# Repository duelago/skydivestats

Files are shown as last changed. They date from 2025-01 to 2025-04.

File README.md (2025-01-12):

# SkyWin Stats

<h1>Wall mounted instrument that displays jump data</h1>

alti

<h2>End user installation instructions</h2>

1. Plug in the Altimeter to the wall with a usb charger and a micro usb-cable<br>
2. Search your wifi networks and connect to SkyWin Stats<br>
3. A captive portal pops up. If not start a browser and go to http://192.168.4.1<br>
4. Give your wifi credentials. The altimeter will get an IP on your wifi network<br>
5. Connect to http://skywinstats.local (You must be connected to the same wifi with your device) <br>
5b. If above does not work. Download the app Fing on your phone and scan your network to figure out the new IP for the Altimeter. (It shows up as skywinstats or Generic device) <br>
5c. Browse your Altimeter webservers IP-address. In my case I got the IP http://192.168.8.111 You have another IP<br>
6. Login on website. user: skydive  passwd: jump<br>
7. Add the url to your dropzone JSON API, SkyWinOne 24.0.1 or later. (Talk to Jesper Löfberg at SkyWin if you don't know how)<br>
   (Demo looks like this: https://demo.skywin.se/api/v1/reports/jump-stats.json )<br>
8. Done! The url is stored in EEPROM and will survive a power failure. The unit will also recalibrate itself if it loses power.

<h2>How to build your own SkyWin stats altimeter</h2>

We use a 3D printed altimeter to show jump statistics from the Skywin database<p>

Demo JSON url from SkyWin: https://demo.skywin.se/api/v1/reports/jump-stats.json<br>
Demo JSON url with more random numbers between reload: http://www.hoppaiplurret.se/jump.php
<br><br>
<b>Example output:</b><br> {"name":"jump-stats","params":"[jumpYear:2025]","result":[{"Total":114,"Other":90,"AFF student":0,"Static line":0,"Manual":0,"Tandem":0,"Video/photo (tandem)":0,"Cockpit":0,"Display":24,"Competition":0}],"size":2}

Idea is to use a stepper motor and a hall sensor and to move the motor to represent the number of jumps made the current season. The first version here is for tandems.<br><br>
<b>Steps to do:</b>
<br>
- 3D print the parts. It is easiest on a Bambulab with AMS, but possible on a normal printer with two color changes.Print the two back covers with connectors so you can open up the construction after it is finished. 

<b>Buy the following:</b><br>
- Wemos d1 mini v3 :https://www.aliexpress.com/item/4000030041652.html<br>
- Stepper motor with driver board: 28BYJ-48-5V + Driver Board ULN2003: https://www.aliexpress.com/item/1005006781616785.html<br>
- KY-024 hall sensor: https://www.aliexpress.com/item/1005007847486915.html<br>
- Magnets: https://www.aliexpress.com/item/1005004351705901.html<br>
- M 2.5 screws<br>
- Dupont cables for soldering<br>
- Superglue to glue the 3D printed part for the components to the backside of the watchface<br>
- Microusb cable
koppling

You need to press fit 3 magnets to the altimeter arrow. One drop of super glue is also good for safety measures so you don't lose the magnets. Make sure that you place the magnets in the correct direction. The hall sensor will only work with the correct polarity. When set, play around with the calibaration setting in the code to make sure the arrow calibrates to 0 at boot. It can differ a few degrees depending on the position of the hall sensor.

Compile the code in Arduino IDE. Add the ESP8266 framework and the necessary libraries.

magnet

konstruktion


<br>

<br>

<br>


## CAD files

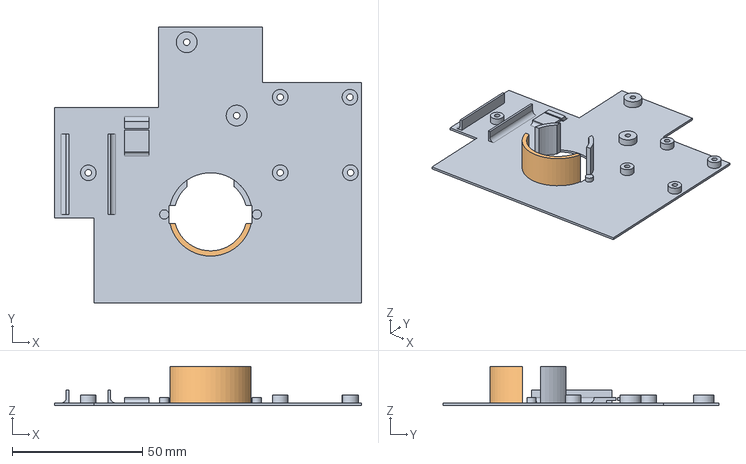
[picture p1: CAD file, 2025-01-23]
barigo-components.step
118.0 x 106.0 x 15.0 mm

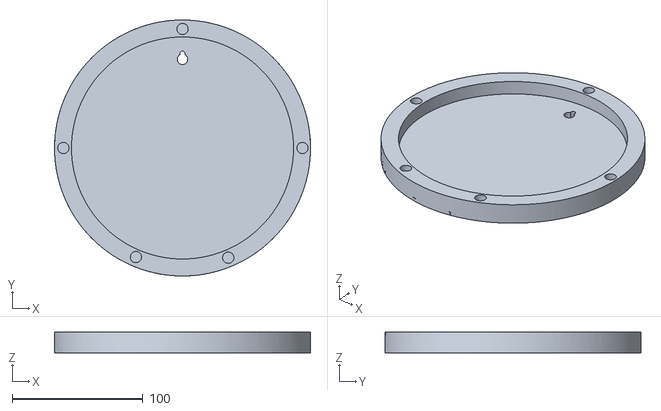
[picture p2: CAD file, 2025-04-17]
urverk/barigo-back-cover-part2-utan-usb.stl
196.0 x 196.0 x 15.8

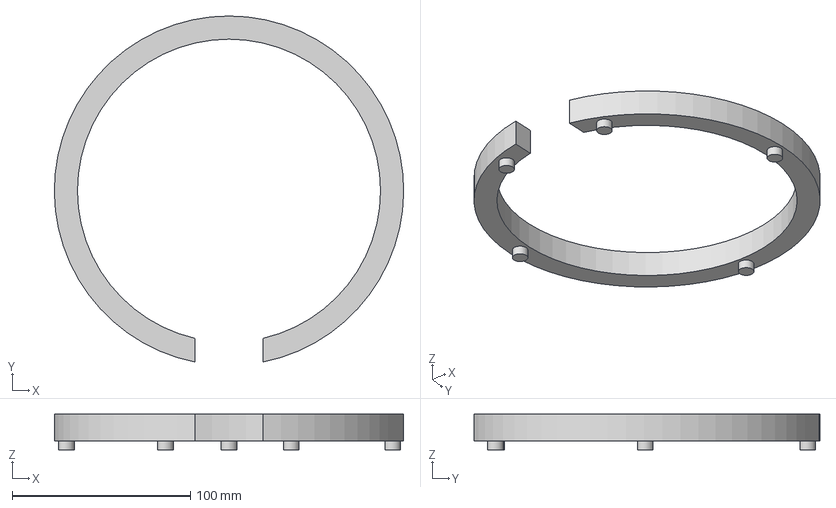
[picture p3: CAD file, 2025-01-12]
barigo-back-cover-part1.step
196.0 x 194.1 x 20.0 mm

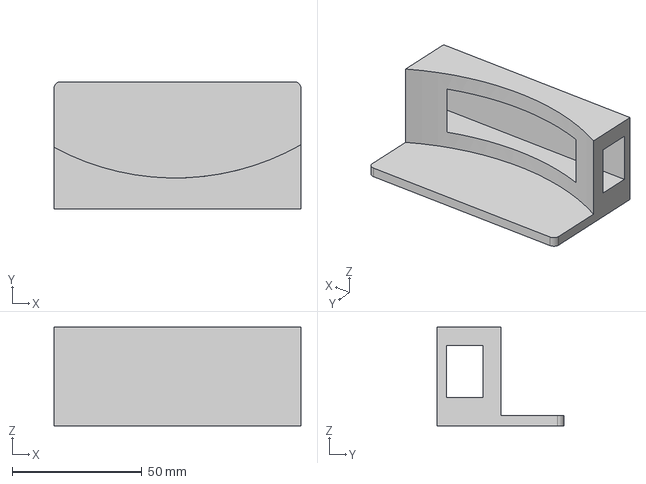
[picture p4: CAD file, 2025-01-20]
urverk/barigo-table-stand.step
95.0 x 49.0 x 38.0 mm

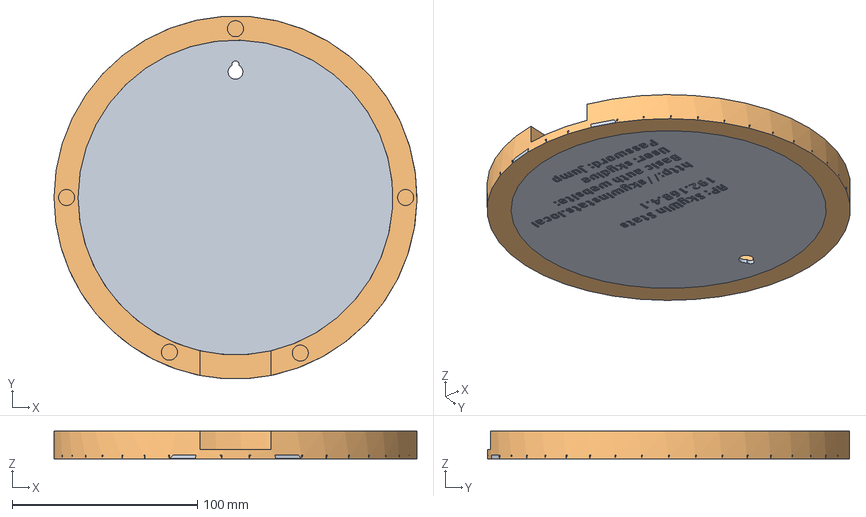
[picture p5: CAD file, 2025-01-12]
barigo-back-cover-part2.step
196.0 x 195.6 x 15.0 mm

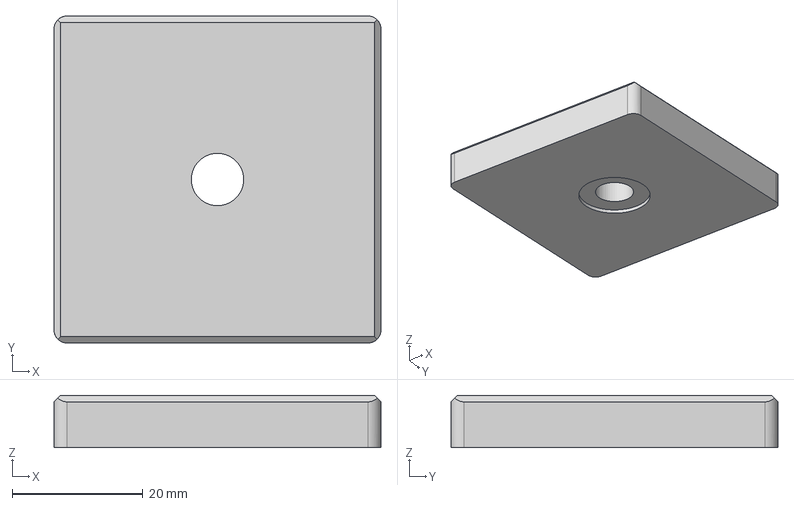
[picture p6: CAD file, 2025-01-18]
urverk/barigo-clock-spacer.step
50.0 x 50.0 x 8.00 mm

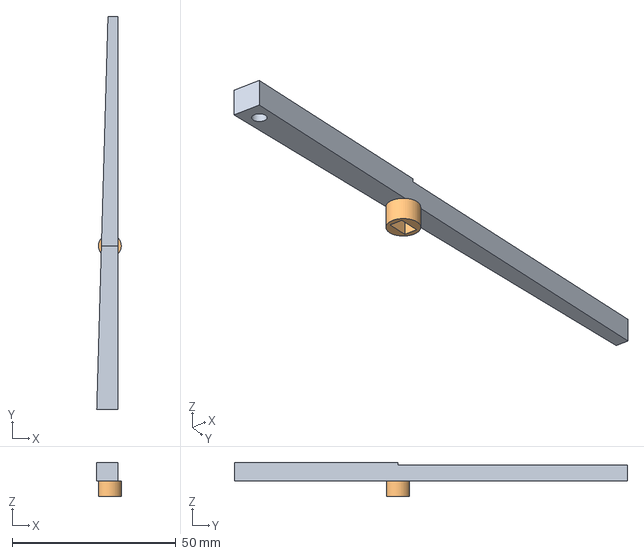
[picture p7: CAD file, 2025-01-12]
barigo-arrow.step
7.50 x 120.0 x 10.4 mm

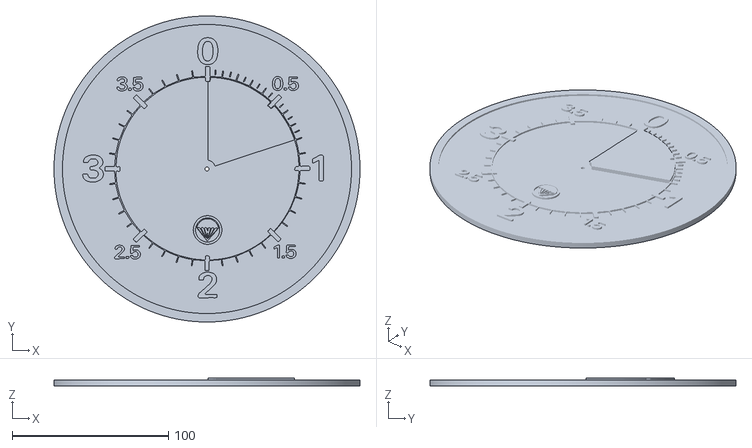
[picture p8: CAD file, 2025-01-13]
urverk/barigo-alternative-face.stl
195.9 x 195.9 x 5.04

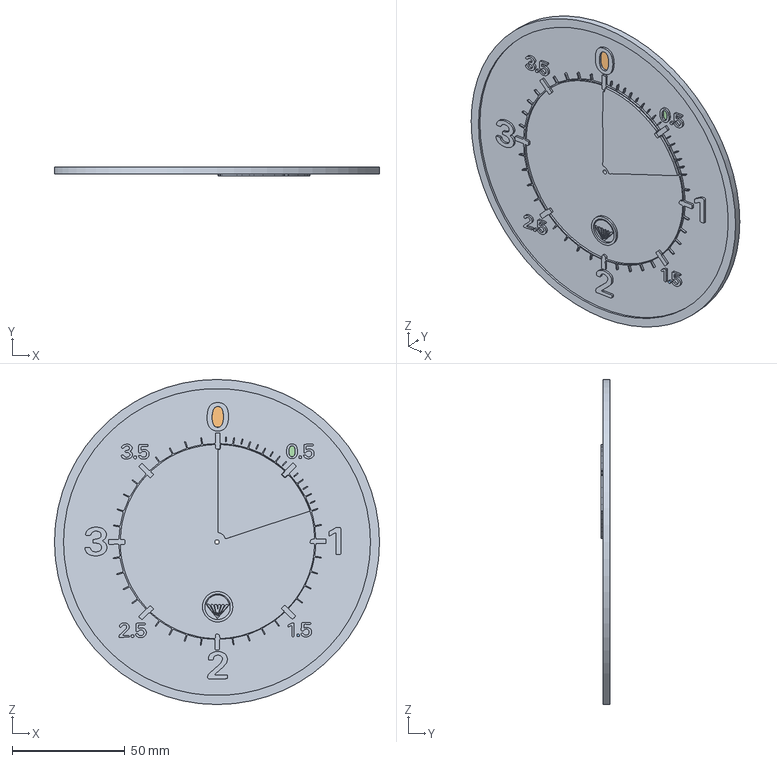
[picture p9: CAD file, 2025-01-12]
barigo-alternative-face.step
144.0 x 4.00 x 144.0 mm

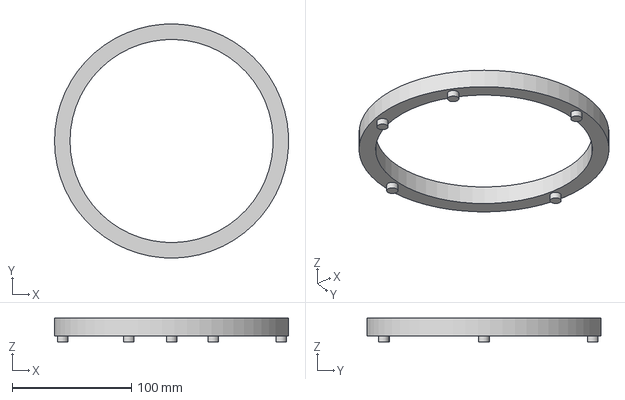
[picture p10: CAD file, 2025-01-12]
urverk/barigo-back-cover-part1-utan-usb.step
195.9 x 195.9 x 20.0 mm

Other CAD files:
urverk/barigo-face.stl
barigo-face.step

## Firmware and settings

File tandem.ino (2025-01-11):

#include <ESP8266WiFi.h>
#include <ESP8266HTTPClient.h>
#include <ESP8266WebServer.h>
#include <ESP8266mDNS.h>
#include <ArduinoJson.h>
#include <AccelStepper.h>
#include <WiFiManager.h>
#include <EEPROM.h>
#include <ElegantOTA.h>

// Pin definitions
#define IN1 D1
#define IN2 D2
#define IN3 D3
#define IN4 D4
#define HALL_SENSOR_PIN D5

// Variables
ESP8266WebServer server(80);
AccelStepper stepper(AccelStepper::HALF4WIRE, IN1, IN3, IN2, IN4);
String jsonUrl;
int previousTandem = 0;
unsigned long lastFetchTime = 0;

// === Kalibreringsvinkel ===
// Justera denna vinkel för att kalibrera pilens position
const int CALIBRATION_ANGLE = 199;  // Ändra värdet här för att justera vinkel

// === Tid mellan uppdatering ===
// const unsigned long fetchInterval = 20000; // 20 seconds for testing
const unsigned long fetchInterval = 3600000; // Kolla en gång per timme 

const char* authUsername = "skydive";
const char* authPassword = "jump";

// Calibration state
bool isCalibrating = true;

void setup() {
  Serial.begin(115200);
  EEPROM.begin(512);

  // Configure Hall sensor pin
  pinMode(HALL_SENSOR_PIN, INPUT_PULLUP);

  // Load URL from EEPROM
  loadUrlFromEEPROM();

  WiFiManager wifiManager;
  wifiManager.autoConnect("SkyWin Stats");
  Serial.println("WiFi connected!");

  // Initialize mDNS
  if (MDNS.begin("skywinstats")) {
    Serial.println("mDNS responder started. Access your ESP at http://skywinstats.local");
    // Add web service to mDNS
    MDNS.addService("http", "tcp", 80);
  } else {
    Serial.println("Error starting mDNS responder!");
  }

  // Set up web server routes
  server.on("/", HTTP_GET, handleRoot);
  server.on("/set-url", HTTP_POST, handleSetUrl);
  ElegantOTA.begin(&server);
  server.begin();
  Serial.println("Web server started.");

  // Configure stepper motor
  stepper.setMaxSpeed(1000);
  stepper.setAcceleration(500);

  // Start calibration process in non-blocking way
  calibrateToZero();
}

void loop() {
  server.handleClient();
  MDNS.update(); // Handle mDNS requests
  

  // Check if it's time to fetch the data
  if (millis() - lastFetchTime >= fetchInterval) {
    fetchData();
    lastFetchTime = millis();
  }

  // If still calibrating, let the motor run in background
  if (isCalibrating) {
    stepper.run();
  } else {
    // If the motor is not moving, disable the outputs to avoid unnecessary torque
    if (stepper.distanceToGo() == 0) {
      stepper.disableOutputs();  // Disable motor outputs to stop torque
    }
  }
}


void calibrateToZero() {
  Serial.println("Calibrating to zero position...");
  delay(1000);  // Delay to allow initialization

  // Move motor in reverse direction continuously
  stepper.setMaxSpeed(500);
  stepper.setSpeed(-500);
  stepper.moveTo(-1000000);  // Arbitrary large negative number to keep the motor moving

  while (true) {
    stepper.run();  // Continuously run the motor

    // Print status occasionally to reduce flooding
    static unsigned long lastPrintTime = 0;
    if (millis() - lastPrintTime > 500) {
      Serial.println("Searching for Hall sensor...");
      lastPrintTime = millis();
    }

    // If the Hall sensor is triggered, stop the motor and set current position to zero
    if (digitalRead(HALL_SENSOR_PIN) == LOW) {  // Assuming LOW indicates sensor triggered
      stepper.stop();  // Stop the motor
      stepper.setCurrentPosition(0);  // Set the current position to zero
      Serial.println("Hall sensor detected! Setting current position to zero.");

      // Move stepper to get to 0. Adjust the degrees so the arrow is straight up
      int stepsFor110Degrees = -2048 * CALIBRATION_ANGLE / 360;  // Calculate steps for CALIBRATION_ANGLE degrees
      stepper.moveTo(stepsFor110Degrees);
      stepper.runToPosition();  // Move and stop

      // Update the new zero point
      stepper.setCurrentPosition(0);
      Serial.println("New zero point set after moving " + String(CALIBRATION_ANGLE) + " degrees to 0");

      isCalibrating = false;  // Mark calibration as done
      break;
    }
  }
}


void fetchData() {
  if (WiFi.status() == WL_CONNECTED && jsonUrl.length() > 0) {
    WiFiClient client;
    HTTPClient http;

    http.begin(client, jsonUrl);

    int httpCode = http.GET();
    if (httpCode == HTTP_CODE_OK) {
      String payload = http.getString();
      Serial.println("Data fetched: " + payload);

      // Update the JSON buffer size to fit the new structure
      DynamicJsonDocument doc(2048);
      DeserializationError error = deserializeJson(doc, payload);

      if (error) {
        Serial.println("Failed to parse JSON!");
        return;
      }

      // Access the "result" array and find "Tandem"
      int tandem = doc["result"][0]["Tandem"];
      Serial.println("Tandem: " + String(tandem));

      // Handle values above 4000
      int baseSteps = map(min(tandem, 4000), 0, 4000, 0, 4096);
      int extraSteps = (tandem > 4000) ? tandem - 4000 : 0;
      int totalSteps = baseSteps + extraSteps;

      // Calculate steps to move
      int stepsToMove = totalSteps - stepper.currentPosition();
      stepper.moveTo(totalSteps);

      // Re-enable motor before moving
      stepper.enableOutputs();

      // Run the motor to the new position
      stepper.runToPosition();

      previousTandem = tandem;

      // After movement, disable the motor to avoid torque
      stepper.disableOutputs();
    } else {
      Serial.println("Error fetching data: " + String(httpCode));
    }

    http.end();
  } else {
    Serial.println("WiFi not connected or URL not set");
  }
}


void handleRoot() {
  if (!server.authenticate(authUsername, authPassword)) {
    return server.requestAuthentication();
  }

  String html = R"rawliteral(
    <!DOCTYPE html>
    <html lang="en">
    <head>
      <meta charset="UTF-8">
      <meta name="viewport" content="width=device-width, initial-scale=1.0">
      <title>SkyWin Stats</title>
      <style>
        body {
          font-family: 'Arial', sans-serif;
          background-color: #f0f8ff;
          margin: 0;
          padding: 20px;
        }
        h1 {
          color: #333;
          text-align: center;
        }
        h3 {
          color: #696969;
          text-align: center;
        }
        form {
          max-width: 400px;
          margin: 0 auto;
          background-color: #ffffff;
          padding: 20px;
          border-radius: 10px;
          box-shadow: 0 4px 8px rgba(0, 0, 0, 0.1);
        }
        label {
          display: block;
          margin-bottom: 8px;
          font-weight: bold;
        }
        input[type="text"] {
          width: 100%;
          padding: 10px;
          margin-bottom: 20px;
          border: 1px solid #ccc;
          border-radius: 5px;
        }
        input[type="submit"] {
          width: 100%;
          padding: 10px;
          background-color: #007bff;
          color: #fff;
          border: none;
          border-radius: 5px;
          cursor: pointer;
        }
        input[type="submit"]:hover {
          background-color: #0056b3;
        }
        a {
          display: block;
          text-align: center;
          margin-top: 20px;
          color: #007bff;
          text-decoration: none;
        }
        a:hover {
          color: #0056b3;
        }
        @media (max-width: 600px) {
          body {
            padding: 10px;
          }
          form {
            padding: 15px;
          }
        }
      </style>
    </head>
    <body>
      <h1>SkyWin Stats</h1>
      <form action='/set-url' method='POST'>
        <label for='url'>JSON URL:</label>
        <input type='text' id='url' name='url' value=')rawliteral" + jsonUrl + R"rawliteral('>
        <input type='submit' value='Save'>
      </form>
      <a href='/update'>Firmware Update (OTA)</a>
      <p></p>
      <h3>SkyWinOne 24.0.1 or newer needed for it to work<br>Demo URL to fetch random number of jumps:<br> http://www.hoppaiplurret.se/jump.php </h3><p></p>
    </body>
    </html>
  )rawliteral";

  server.send(200, "text/html", html);
}

void handleSetUrl() {
  if (!server.authenticate(authUsername, authPassword)) {
    return server.requestAuthentication();
  }

  if (server.method() == HTTP_POST) {
    jsonUrl = server.arg("url");
    saveUrlToEEPROM(jsonUrl);
    server.send(200, "text/html", "<html><body><h1>URL Saved!</h1><a href='/'>Back to Home</a></body></html>");
  } else {
    server.send(405, "text/plain", "Method Not Allowed");
  }
}

void loadUrlFromEEPROM() {
  char urlBuffer[100];
  for (int i = 0; i < sizeof(urlBuffer); i++) {
    urlBuffer[i] = EEPROM.read(i);
  }
  jsonUrl = String(urlBuffer);
  jsonUrl.trim();
  Serial.println("Loaded URL: " + jsonUrl);
}

void saveUrlToEEPROM(String url) {
  for (int i = 0; i < url.length() && i < 100; i++) {
    EEPROM.write(i, url[i]);
  }
  EEPROM.write(url.length(), '\0'); // Null-terminate the string
  EEPROM.commit();
  Serial.println("URL saved to EEPROM: " + url);
}

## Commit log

2025-01-08 Add files via upload
    File to mount stepper motor, Wemos D1 mini v3 and hall sensor
    [barigo-components.step]
2025-01-10 Add files via upload
    Split this file in two in Prusa slicer and add connectors to be able to open the construction after it is finished
    [barigo-back-cover-split.step]
2025-01-12 A simple table stand
    Quick and dirty table stand
    [barigo-table-stand.step]
2025-01-12 Add files via upload
    Back cover utan hål för USB-sladd. Används för de som vill stoppa i ett vanligt urverk och sisa tiden. Printas i två delar så man enkelt kan öppna upp och byta batteri
    [barigo-back-cover-part1-utan-usb.step, barigo-back-cover-part2-utan-usb.step]
2025-01-18 Add files via upload
    Köpte ett urverk från AliExpress och gjorde denna detalj som sitter mellan urverket och urtavlan på baksidan för att få lagom avstånd från visarna till urtavlan.
    [barigo-clock-spacer.step]
2025-04-17 Add files via upload
    Utan text för urverk utan wifi
    [barigo-back-cover-part2-utan-usb.stl]
